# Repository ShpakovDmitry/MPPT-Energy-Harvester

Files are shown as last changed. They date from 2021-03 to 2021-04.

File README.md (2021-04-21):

`revision:0.0.2 stage:testing`
#### Description
Solar energy harvester with MPPT controller for low power devices.\
Is configurable for a variety of setups in easy way - by simply using solderbridges on PCB.\
#### Features
* input voltage operation range from 50 mV to 5V
* starting from 3 µW energy harvesting
* 550 mW maximal power harvesting
* selectable Voc ratios of 70, 75, 85 and 90%
* cold start from 380 mV
* two integrated LDOs - low and high voltage
* selectable output voltage
* configurable to use with Li-ion, LiFePO4, NiMH and Supercapacitor(with/without balance) energy storages
* status pins
* 24x24 mm size

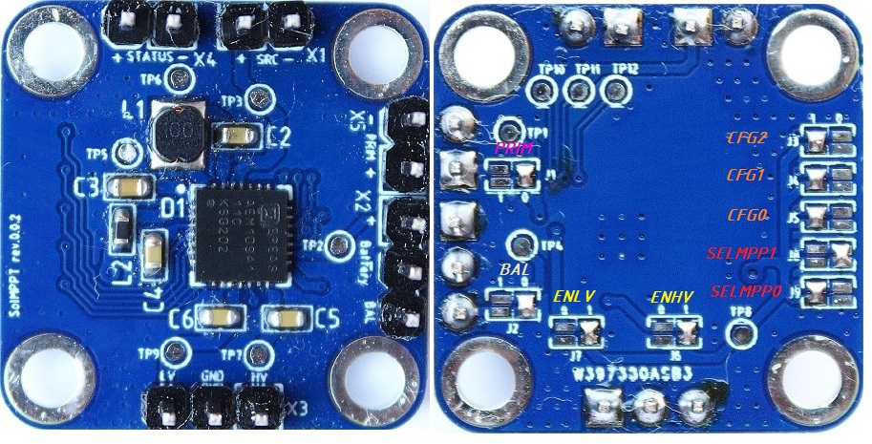
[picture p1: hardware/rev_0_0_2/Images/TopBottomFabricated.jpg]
fabricated


#### Project outputs:
* Schematics
* BOM
* GERBER

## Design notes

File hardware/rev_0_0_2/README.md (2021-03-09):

###### Schematics

schematics

###### BOM

BOM

###### Top Bottom view
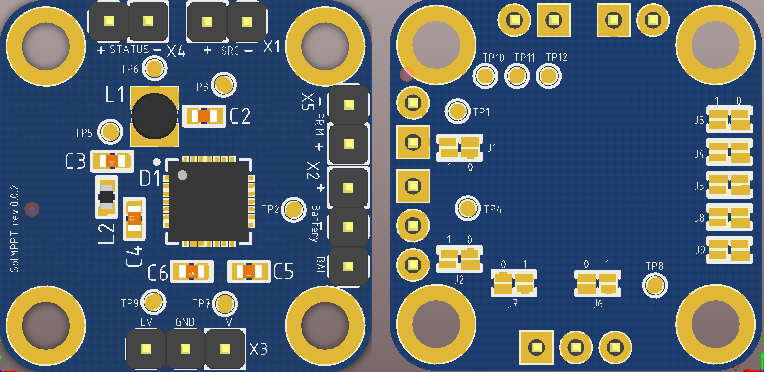
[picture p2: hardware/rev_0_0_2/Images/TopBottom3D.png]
top\_bottom\_view


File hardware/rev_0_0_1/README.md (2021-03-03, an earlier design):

###### Revision 0.0.1 flaws
Schematic:
1. `L1` has incorrect connection. Should be connected to `BUFSRC` not to `BOOST`.

PCB:
1. Via's for `C1` are quite small. Inner diameter should be bigger.
1. Silkscreen for `X3` is big compared to other `X` connectors.
1. Silkscreen for `G1, G2` is upside-down.
1. Top solder mask on `D1` `EPAD` should be removed.
1. Mounting holes should be connected to `GND` net.
1. Ground connection for `G1, G2` should be without thermal barrier. This is for higher currents.

###### Schematics

schematics

###### BOM

BOM

###### View
Rendered PCB view
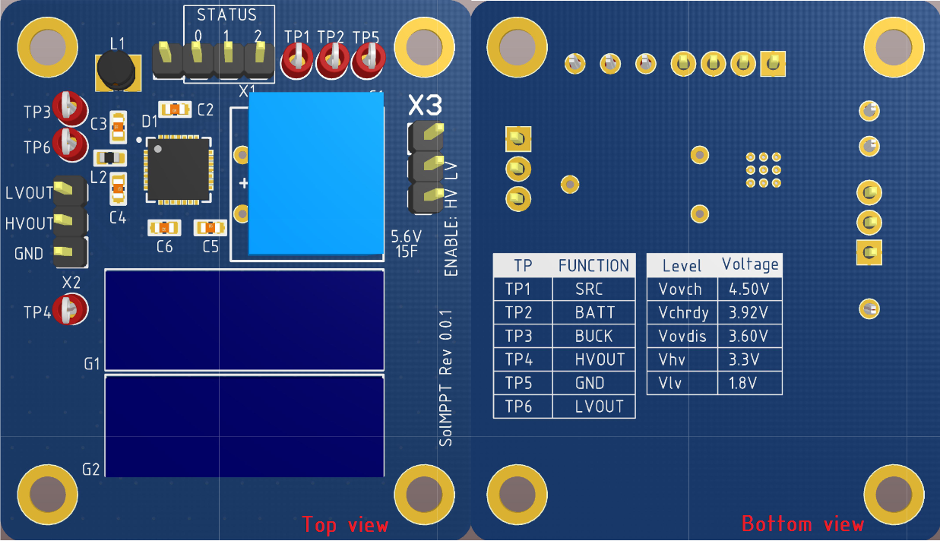
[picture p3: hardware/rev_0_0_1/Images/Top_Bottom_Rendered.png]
Rendered view


Fabricated PCB view
Fabricated view

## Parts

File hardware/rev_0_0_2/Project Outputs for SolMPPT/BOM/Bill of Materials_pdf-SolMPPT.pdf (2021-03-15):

Comment | Designator | Manufacturer | PartNumber | Quantity | Value
Fixed inductor, 10μH, ±20%, SDR0302, 900mA, -40...+125°C | L1 | Bourns | SDR0302-100ML | 1 | 10μH
Connector, 3pin, 2.54mm, 500VAC, 3A | X2, X3 | Connfly | PLS-3 | 2
Connector, 2pin, 2.54mm, 500VAC, 3A | X1, X4, X5 | Connfly | PLS-2 | 3
Fixed inductor, 10μH, ±20%, 0603, 250mA, -55...+125°C | L2 | TDK Corporation | MLZ1608M100WT000 | 1 | 10μH
Ceramic capacitor, 22μF, X5R, ±20%, 10V, 0603, -55...+85°C | C3 | Murata Electronics | GRM188R61A226ME15D | 1 | 22μF
Ceramic capacitor, 10μF, X5R, ±20%, 10V, 0603, -55...+85°C | C2, C4, C5, C6 | Murata Electronics | GRM188R61A106ME69D | 4 | 10μF
AEM10941-QFN | D1 | | AEM10941-QFN | 1
TestPoint | TP1, TP2, TP3, TP4, TP5, TP6, TP7, TP8, TP9, TP10, TP11, TP12 | | | 12
ValueManufacturerPartNumber | J1, J2, J3, J4, J5, J6, J7, J8, J9 | | | 9

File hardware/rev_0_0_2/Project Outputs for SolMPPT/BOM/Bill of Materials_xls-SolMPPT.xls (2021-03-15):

Comment | Designator | Manufacturer | PartNumber | Quantity
Fixed inductor, 10μH, ±20%, SDR0302, 900mA, -40...+125°C | L1 | Bourns | SDR0302-100ML | 1
Connector, 3pin, 2.54mm, 500VAC, 3A | X2, X3 | Connfly | PLS-3 | 2
Connector, 2pin, 2.54mm, 500VAC, 3A | X1, X4, X5 | Connfly | PLS-2 | 3
Fixed inductor, 10μH, ±20%, 0603, 250mA, -55...+125°C | L2 | TDK Corporation | MLZ1608M100WT000 | 1
Ceramic capacitor, 22μF, X5R, ±20%, 10V, 0603, -55...+85°C | C3 | Murata Electronics | GRM188R61A226ME15D | 1
Ceramic capacitor, 10μF, X5R, ±20%, 10V, 0603, -55...+85°C | C2, C4, C5, C6 | Murata Electronics | GRM188R61A106ME69D | 4
AEM10941-QFN | D1 |  | AEM10941-QFN | 1

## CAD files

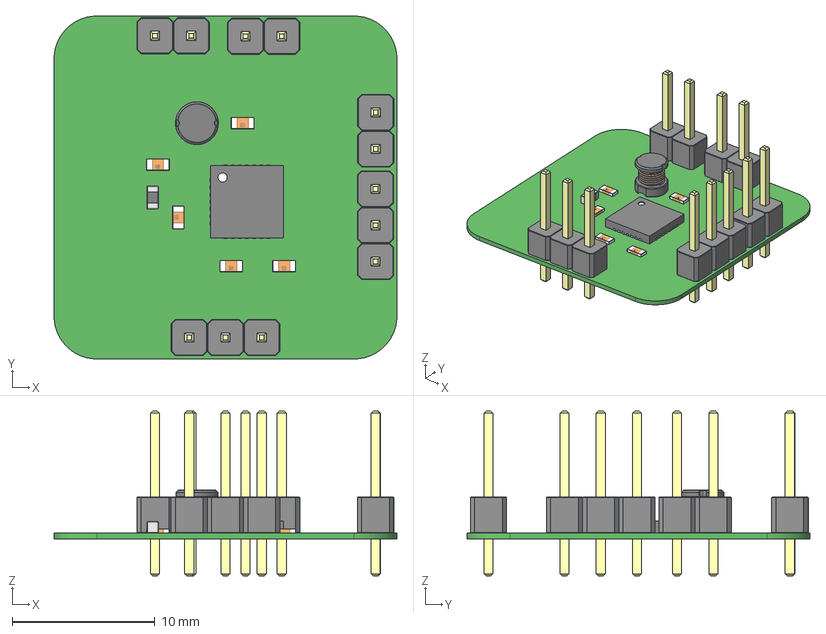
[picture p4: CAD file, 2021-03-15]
hardware/rev_0_0_2/Project Outputs for SolMPPT/ExportSTEP/PCB.step
24.0 x 24.0 x 11.5 mm
Board
Open_CASCADE_STEP_translator_6.8_9.1
Open_CASCADE_STEP_translator_6.8_9.2.1
Thermal_Shape
Open_CASCADE_STEP_translator_6.8_9.4.1 x 28
основание x 12
прямой_штырь x 12
Open_CASCADE_STEP_translator_6.8_17.1.1
Open_CASCADE_STEP_translator_6.8_17.1.2
Open_CASCADE_STEP_translator_6.8_17.2.1
BODY_BOT
BODY_MID
BODY_TOP
LEADS
COIL_BASE
COIL-END x 2
SW3dPS-0603_SMD_Capacitor x 5

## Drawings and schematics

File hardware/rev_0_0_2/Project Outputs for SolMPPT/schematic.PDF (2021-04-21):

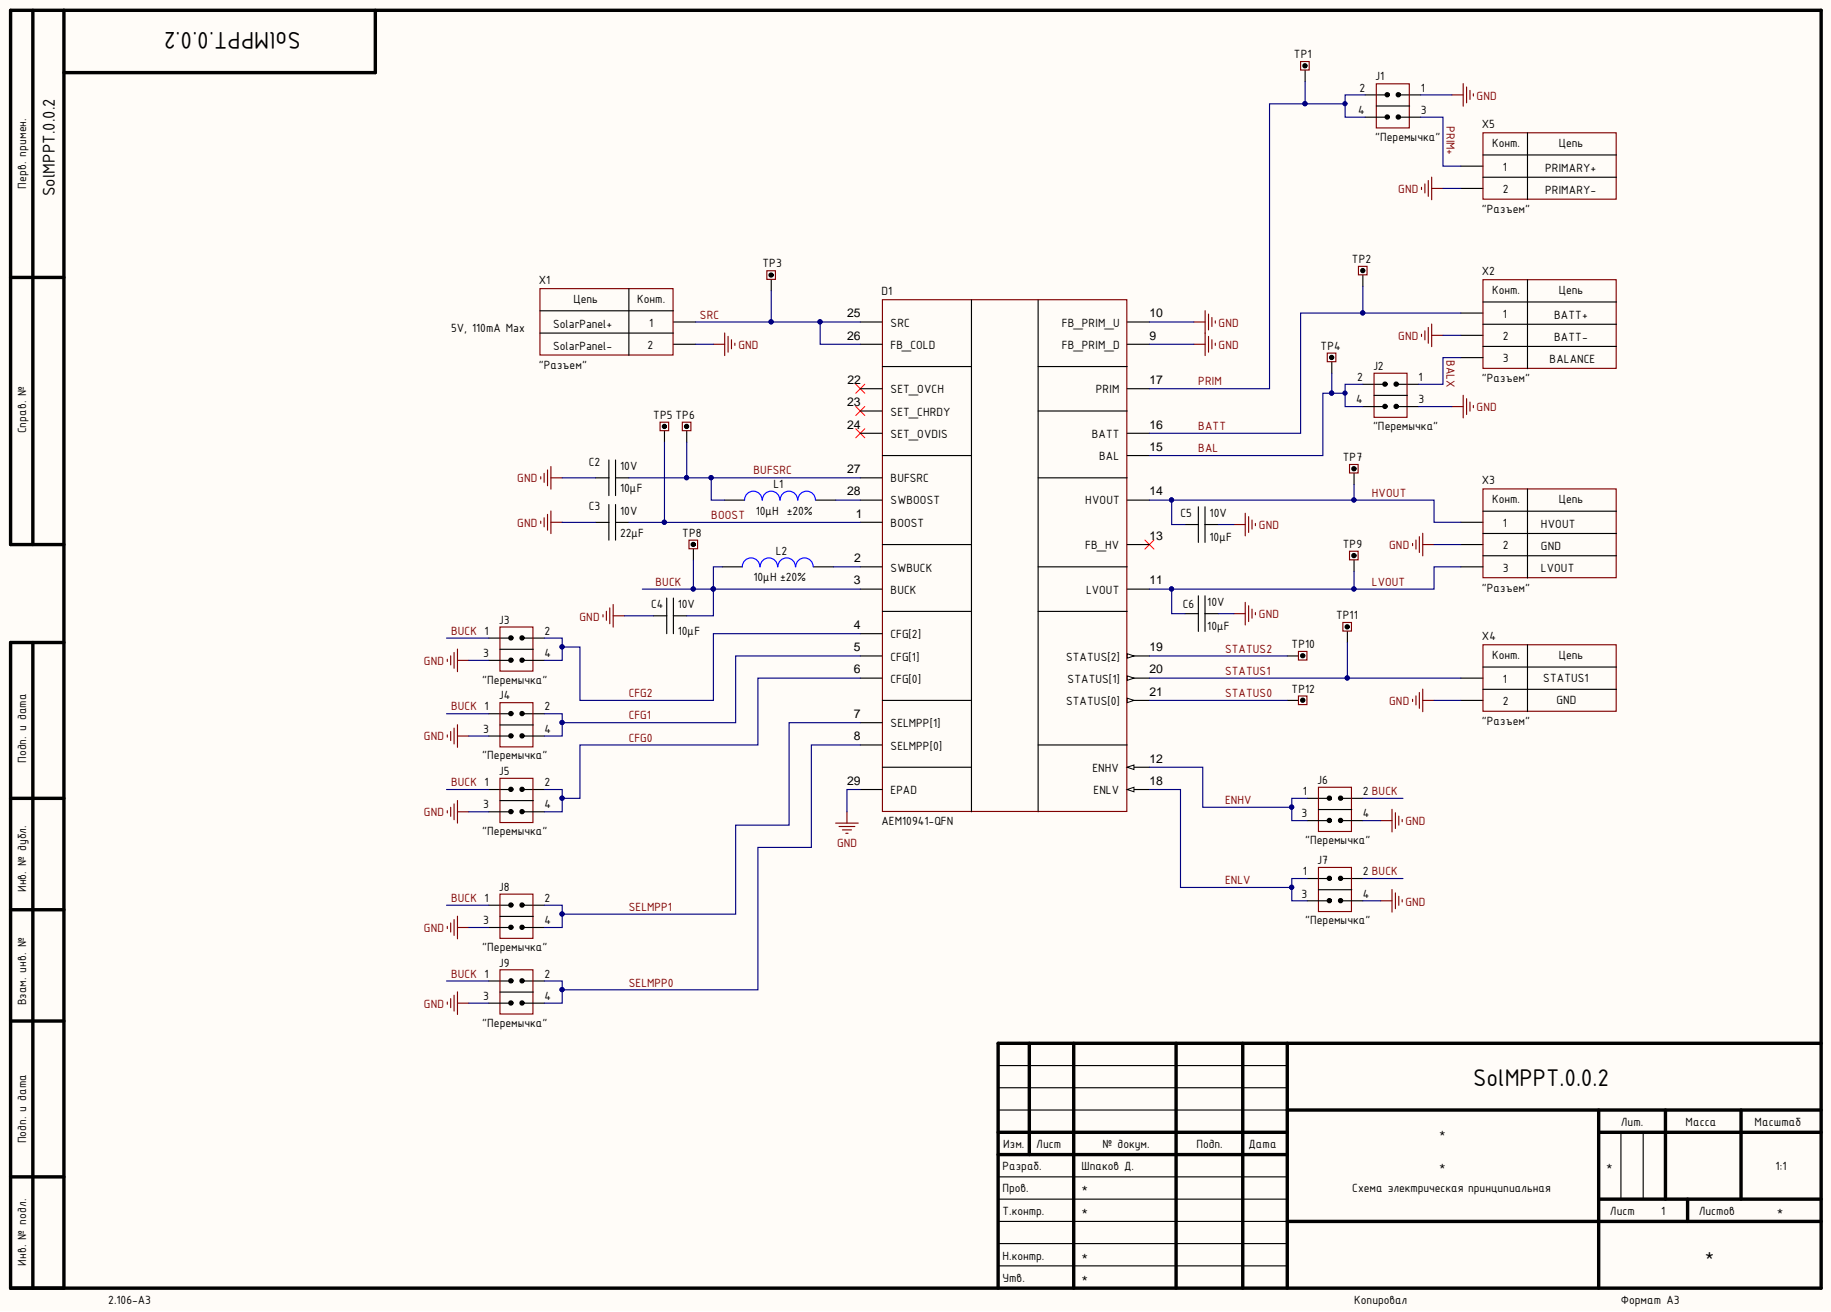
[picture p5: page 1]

Инв. № подл. Инв. № дубл. Подп. и дата Взам. инв. № Подп. и дата Перв. примен. Справ. №

Конт. | Цепь

1 | PRIMARY+

2 | PRIMARY-

1 | HVOUT

3 | LVOUT

CFG2 | 6 | | 20 STATUS1

CFG0 | | | SELMPP[0] 8

EPAD | 18

ENHV

SolMPPT.0.0.2

* * Схема электрическая принципиальная | Лит. | Масса | Масштаб

Изм. | Лист | № докум. | Подп. | Дата | | * | | | 1:1

Разраб. | | Шпаков Д.

Пров. | | *

Т.контр. | * | | | | Лист 1 | Листов *

Н.контр. | *

Утв. | *

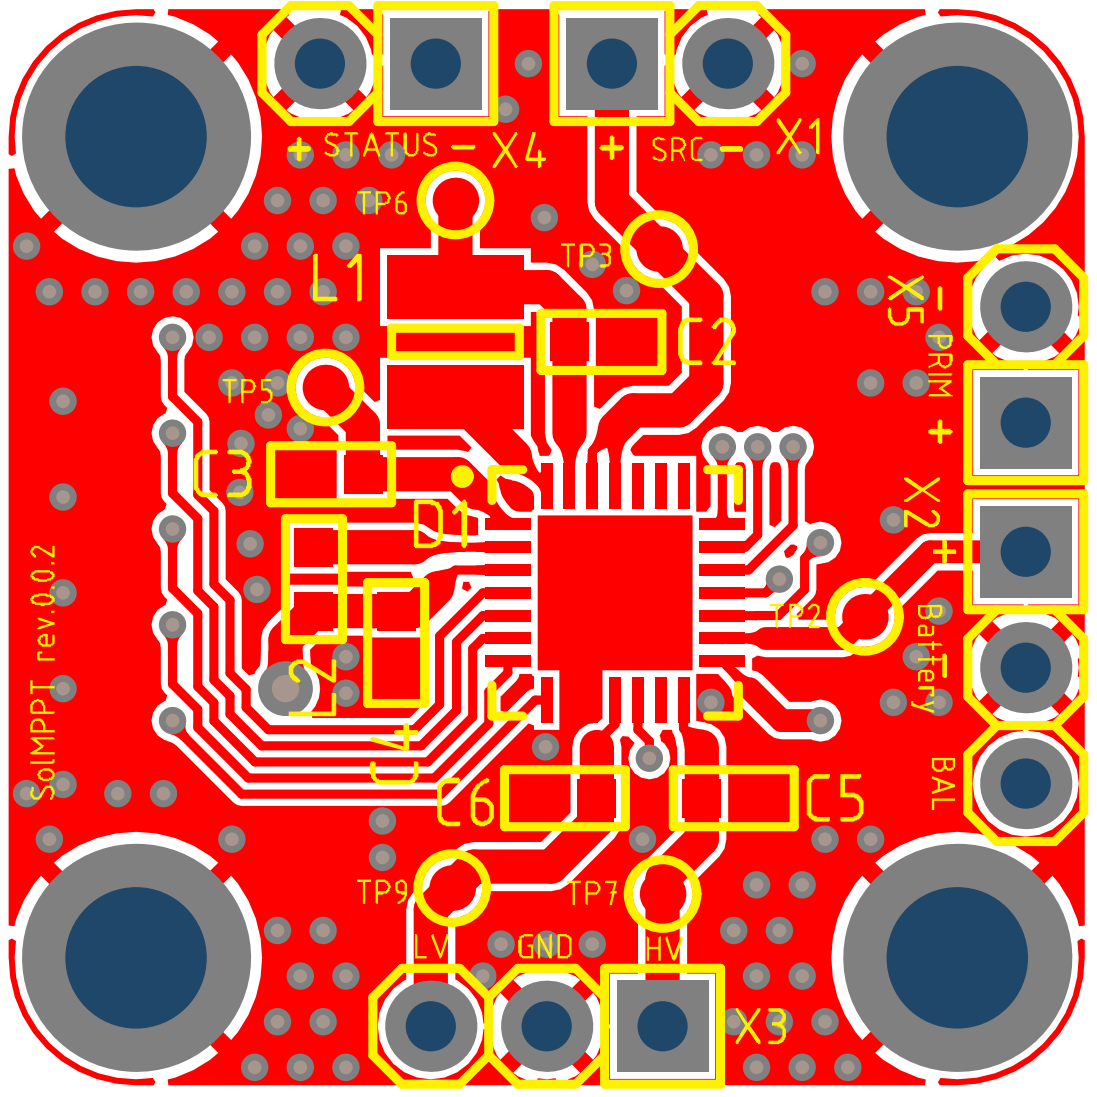
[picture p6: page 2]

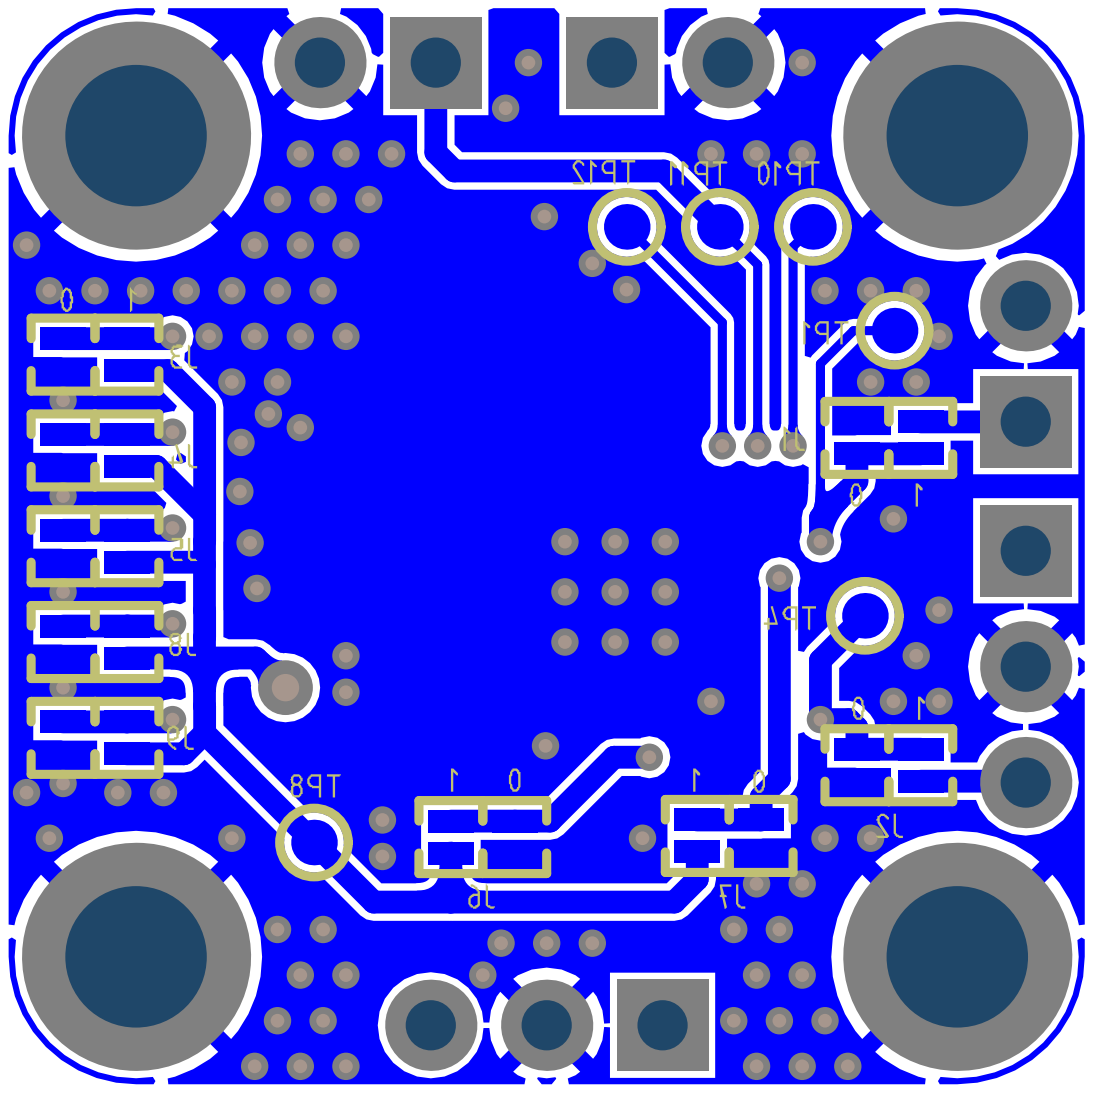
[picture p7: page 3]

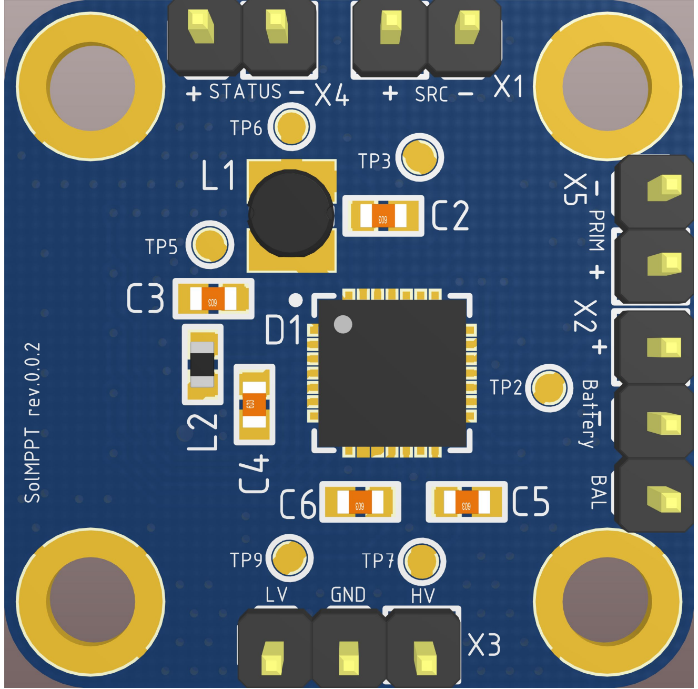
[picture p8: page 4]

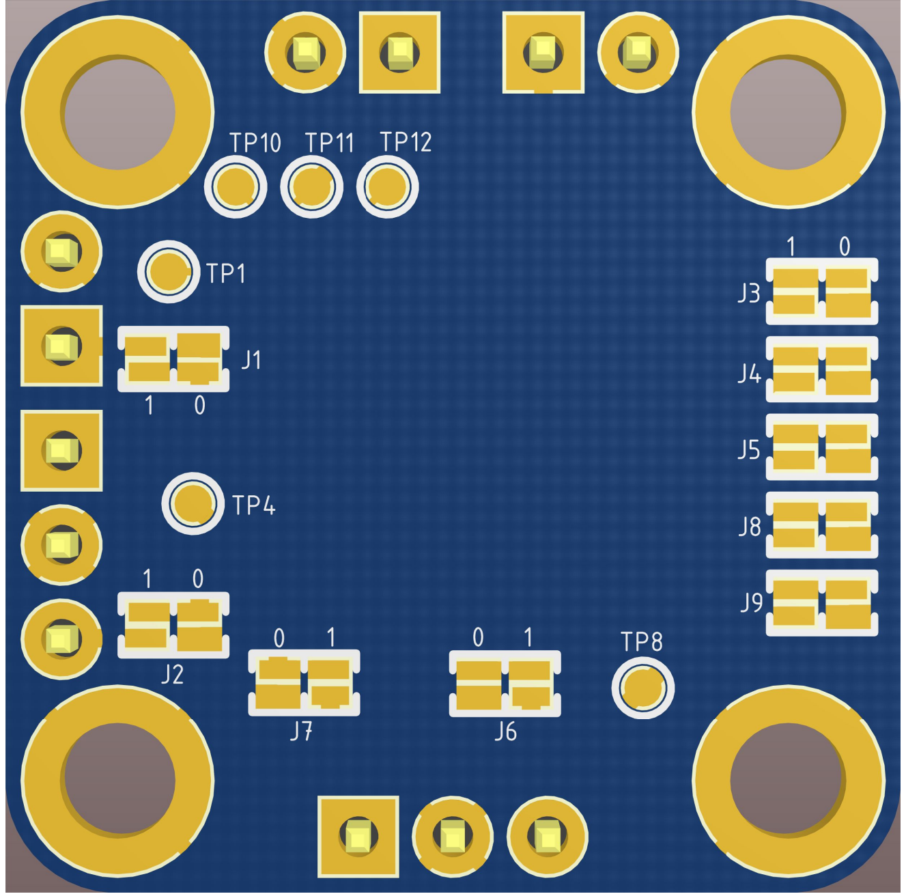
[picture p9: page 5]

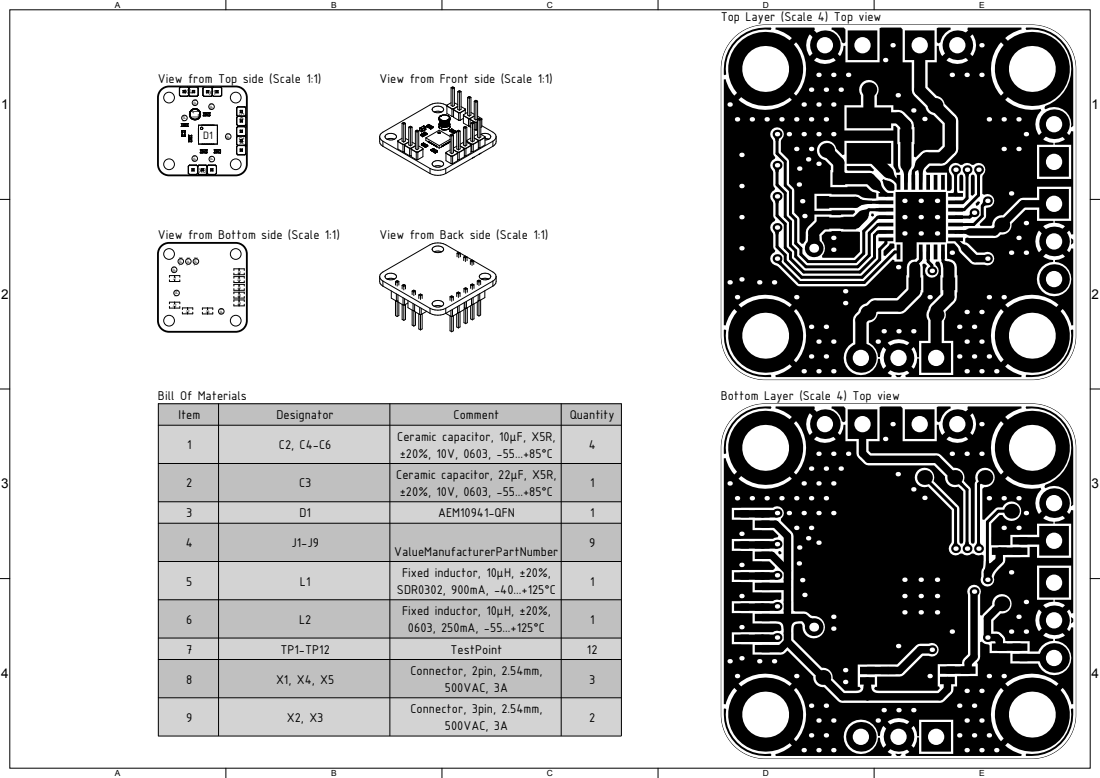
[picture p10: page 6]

Top Layer (Scale 4) Top view

View from Top side (Scale 1:1)

View from Front side (Scale 1:1)

View from Bottom side (Scale 1:1)

View from Back side (Scale 1:1)

Bottom Layer (Scale 4) Top view

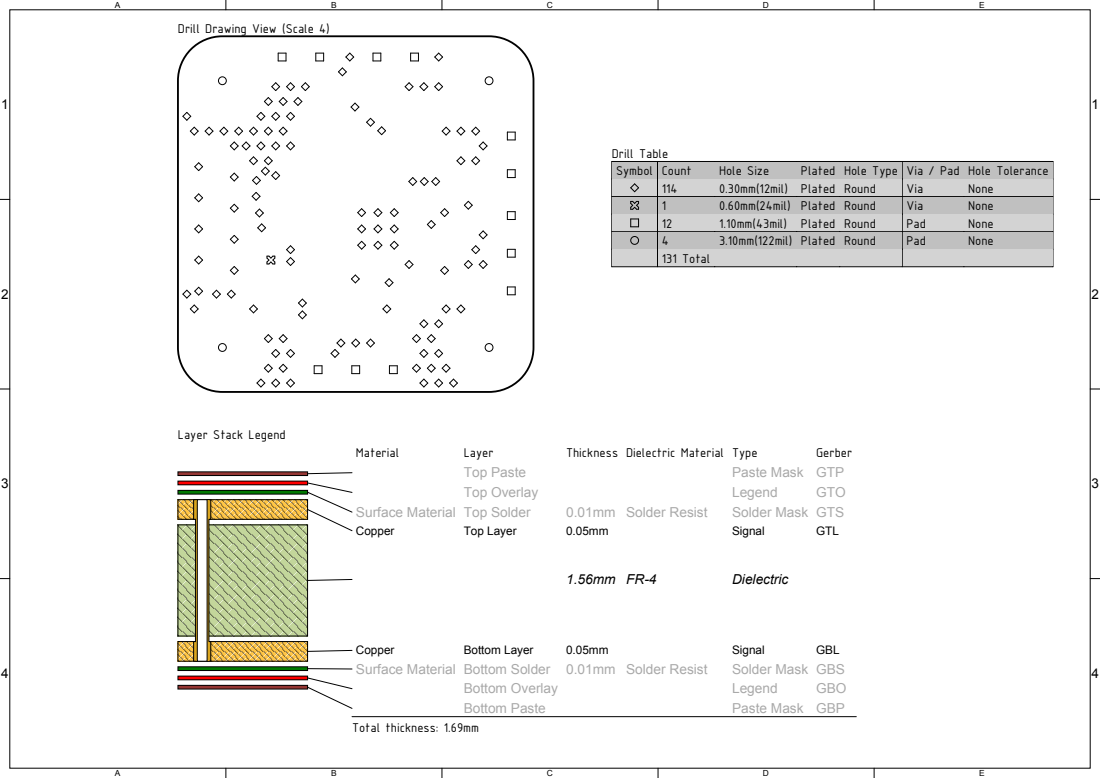
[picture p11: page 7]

Drill Drawing View (Scale 4)

Symbol | Count | Hole Size | Plated | Hole Type | Via / Pad | Hole Tolerance
114 | 0.30mm(12mil) | Plated | Round | Via | None
1 | 0.60mm(24mil) | Plated | Round | Via | None
12 | 1.10mm(43mil) | Plated | Round | Pad | None
4 | 3.10mm(122mil) | Plated | Round | Pad | None
131 Total

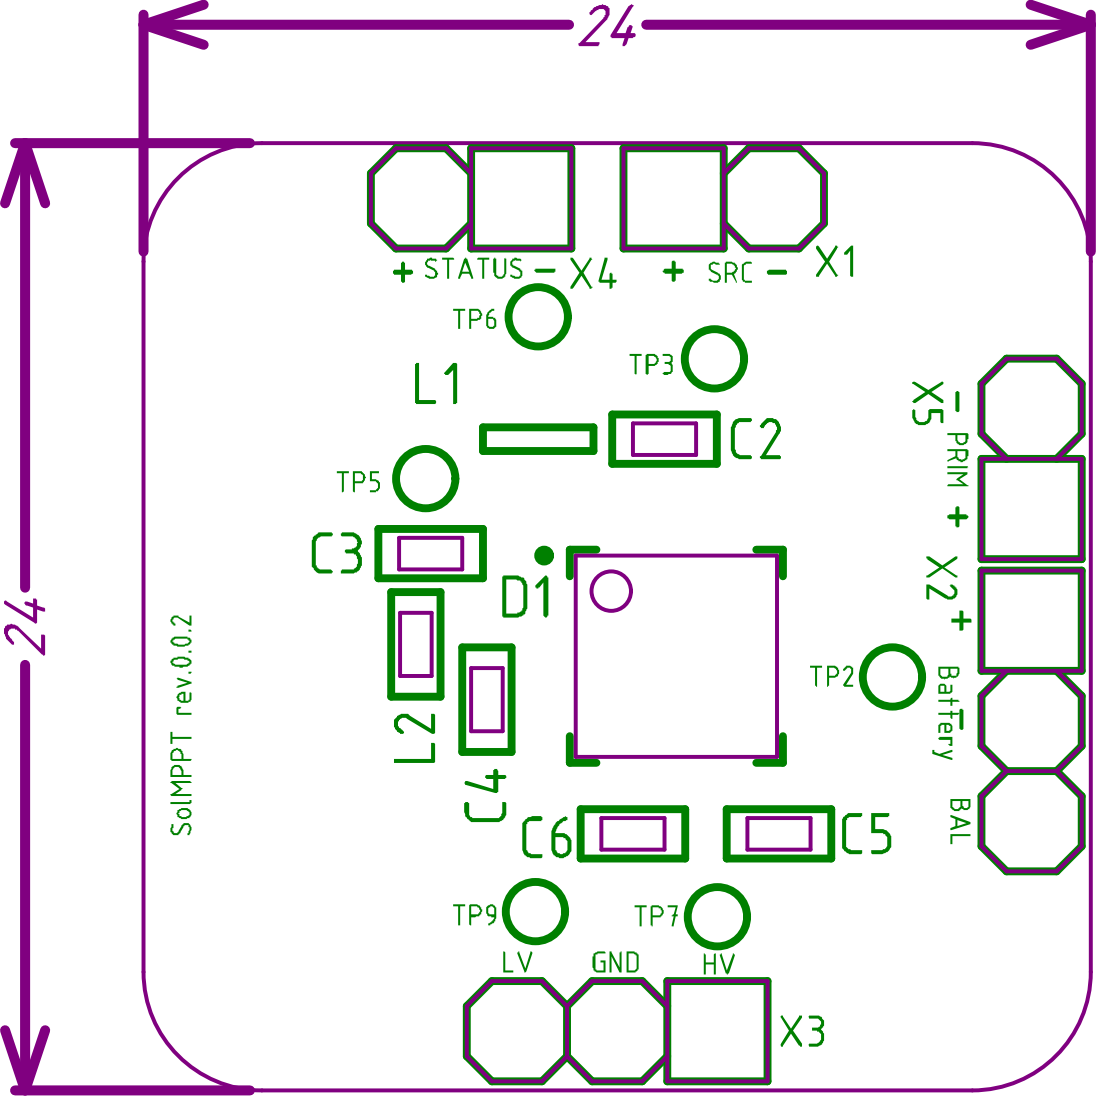
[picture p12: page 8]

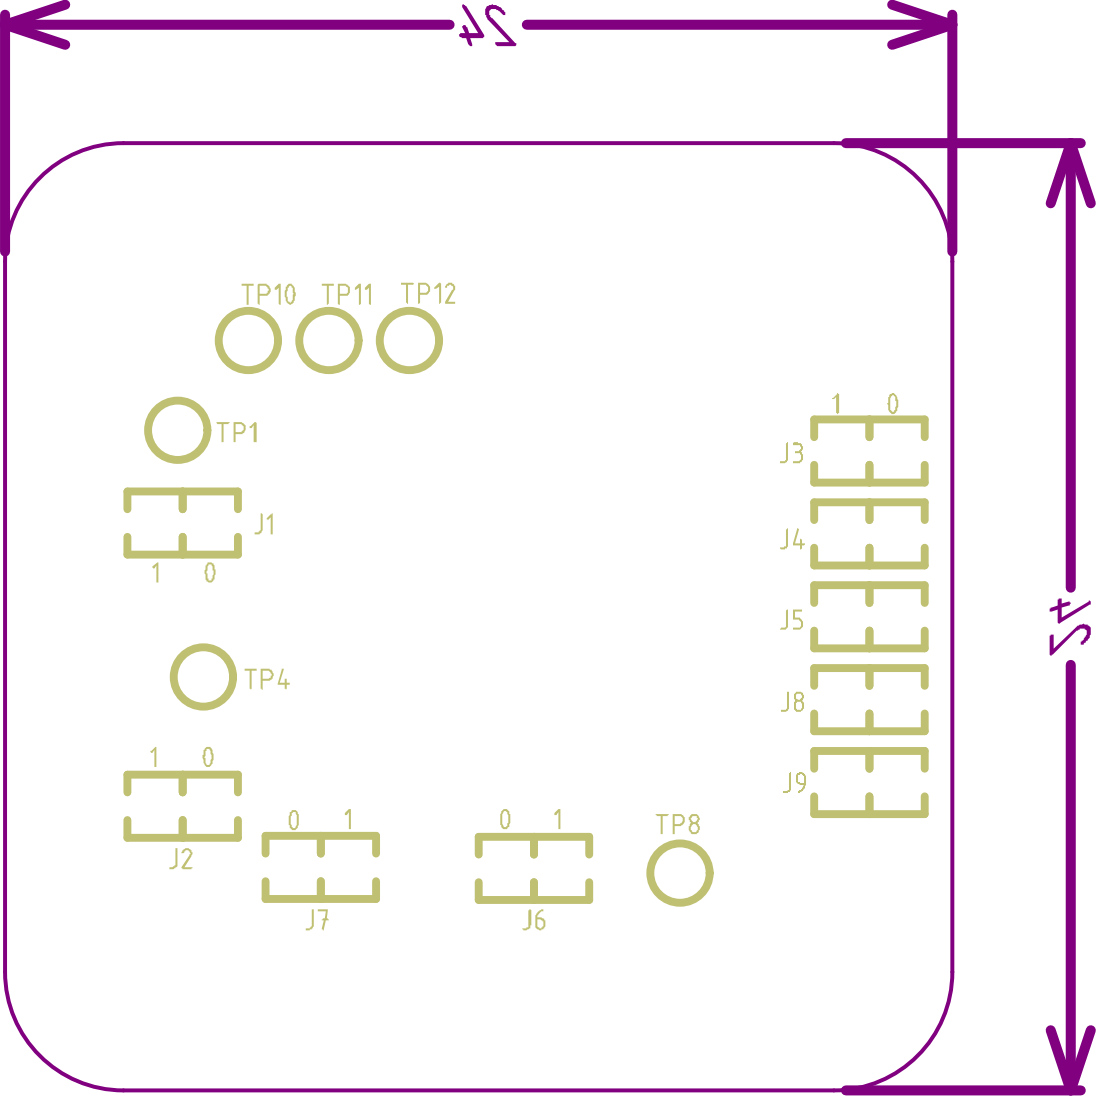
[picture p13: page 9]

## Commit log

2020-11-08 KiCad project init
    [SolarCell.kicad_pcb, SolarCell.sch]
2020-11-08 schematics: information update
    [SolarCell.sch]
2020-11-09 kicad: update
2020-11-10 library: current sense resistor added
2020-11-10 library: 2x1 connector created
2020-11-10 schematics: update
    [SolarCell.sch]
2020-11-10 schematics: components numerated and pdf added
    [SolarCell.sch]
2020-11-11 library: resistor added
2020-11-11 library: resistor updated
2020-11-11 schematics: bypass resistor added
    [SolarCell.sch]
2020-11-12 footprint: initial add
    [SolarCell.sch]
2020-11-12 footprint: KXOB25-14X1F added
2020-11-12 schematics: using four solar cells which could be bypassed
    [SolarCell.sch]
2020-11-14 schematics: voltage sense terminals added
    [SolarCell.sch]
2020-11-14 library: generic diode added
2020-11-14 schematics: bypass diodes added
    [SolarCell.sch]
2020-11-14 schematics: blocking diode added
    [SolarCell.sch]
2020-11-14 footprint: LSM115J shottky diode added
2020-11-17 footprint: L4T12 current sense resistor added
2020-11-17 library: connector updated
2020-11-17 schematics: updated
    [SolarCell.sch]
2020-11-19 library: generic capacitor added
2020-11-19 library: generic NTC resistor added
2020-11-19 library: generic GND added
2020-11-19 library: generic battery added
2020-11-19 schematics: solar energy harvester IC with MPPT added
    [SolarCell.sch]
2020-11-19 library: 2x1 connector added
2020-11-19 library: generic connectors added
2020-11-24 footprint: 1206 resistor added
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2020-11-24 moved KiCad project to separae directory
    [SolarCell.kicad_pcb, SolarCell.sch]
2020-11-24 moved schematics pdf to separate directory
2021-01-27 +) altium initial add
    [PCB.PcbDoc, SolMPPT.PrjPcb, page1.SchDoc]
2021-01-27 -) using Altium instead KiCad
    [SolarCell.kicad_pcb, SolarCell.sch]
2021-01-27 *) minor changes
    [SolMPPT.PrjPcb, page1.SchDoc]
2021-01-28 +) IXYS solar cell added
    [page1.SchDoc]
2021-01-29 +) schematics: Source side added
    [SolMPPT.PrjPcb, page1.SchDoc]
2021-01-30 +) schematics: dummy thermal protection added
    [page1.SchDoc]
2021-01-30 +) schematic: control ports added
    [page1.SchDoc]
2021-01-31 *) schematics: using AEM10941 harvester instead of MAX20361
    [page1.SchDoc]
2021-02-03 +) schematics: supercapacitor added
    [page1.SchDoc]
2021-02-04 +) schematics: added MPPT controller remaining external parts
    [page1.SchDoc]
2021-02-08 +) schematics: connectors and test points added
    [SolMPPT.PrjPcb, page1.SchDoc]
2021-02-08 *)schematics: pin change
    [SolMPPT.PrjPcb, page1.SchDoc]
2021-02-09 *)schematics: changed components values which were deleted occasionally
    [SolMPPT.PrjPcb, page1.SchDoc]
2021-02-10 +)PCB: updated
    [PCB.PcbDoc, page1.SchDoc]
2021-02-11 +)PCB: routing completed
    [PCB.PcbDoc, page1.SchDoc]
2021-02-12 *)PCB: minor changes
    [PCB.PcbDoc]
2021-02-12 +)PCB: informative silkscreen added
    [PCB.PcbDoc]
2021-02-12 *)project: minor changes
    [page1.SchDoc]
2021-02-12 +)BOM,GERBER, NC DRILL: added
    [Bill of Materials-SolMPPT.xls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]
2021-02-12 +) STEP: generated
    [PCB.step]
2021-02-12 +)README: BOM link added
2021-02-13 *)PCB: changed clearance from 5mil to 8mil
    [PCB.PcbDoc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]
2021-02-13 *)Schematics, PCB: LDO voltage enable input added
    [Bill of Materials_xls-SolMPPT.xls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]
2021-02-13 +)PCB: via stiching added
    [Bill of Materials_xls-SolMPPT.xls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]
2021-02-13 +)PCB: gerber .RAR archieve added
2021-02-16 *)PCB: top everlay typo fixed
    [Bill of Materials_xls-SolMPPT.xls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]
2021-02-24 *)PCB: view update
    [Bill of Materials_xls-SolMPPT.xls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]
2021-02-24 *) Outputs: Gerber files added rev0.0.1
2021-02-24 +)PCB: 3D view images added
2021-03-03 *)project: setup for rev_0_0_2
    [Bill of Materials-SolMPPT.xls, Bill of Materials_xls-SolMPPT.xls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]
2021-03-03 +)project: rev_0_0_2 folder created
    [Bill of Materials-SolMPPT.xls, Bill of Materials_xls-SolMPPT.xls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]
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2021-03-03 *)schematic: L1 correctly connected
    [page1.SchDoc]
2021-03-04 *)schematic: all power is connected externaly
    [page1.SchDoc]
2021-03-06 +)schematics: done
    [page1.SchDoc]
2021-03-06 +)schematics: testpads added
    [SolMPPT.PrjPcb, page1.SchDoc]
2021-03-06 +)PCB: components placed
    [PCB.PcbDoc, SolMPPT.PrjPcb, page1.SchDoc]
2021-03-07 +)PCB: minor changes
    [PCB.PcbDoc, page1.SchDoc]
2021-03-08 +)PCB: adother routing job done
    [PCB.PcbDoc, page1.SchDoc]
2021-03-08 *)PCB rerouted becouse cant reach pads
    [PCB.PcbDoc, page1.SchDoc]
2021-03-09 +)PCB: routing finished
    [PCB.PcbDoc, SolMPPT.PrjPcb]
2021-03-09 +)Project: outputs generated
    [Bill of Materials_xls-SolMPPT.xls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]
2021-03-09 *)Outputs: generated
    [Bill of Materials-SolMPPT.xls, Bill of Materials_xls-SolMPPT.xls, PCB.step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]
2021-03-12 *)PCB: GND polygon changed
    [PCB.PcbDoc]
2021-03-15 *)PCB: changed jumper orientation
    [PCB.PcbDoc, SolMPPT.PrjPcb, page1.SchDoc]
2021-03-15 *)PCB: small changes
    [Bill of Materials_xls-SolMPPT.xls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]
2021-03-15 +)Project: gerber files added
2021-04-20 +)dosc: images of soldered PCBs added
2021-04-21 +)image: solderbridge names added
2021-04-21 +)output: draftsman output added
    [SolMPPT.PrjPcb]
2021-04-21 +)output: added layer print
